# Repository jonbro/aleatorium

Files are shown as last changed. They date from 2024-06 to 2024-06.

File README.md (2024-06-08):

# Aleatorium

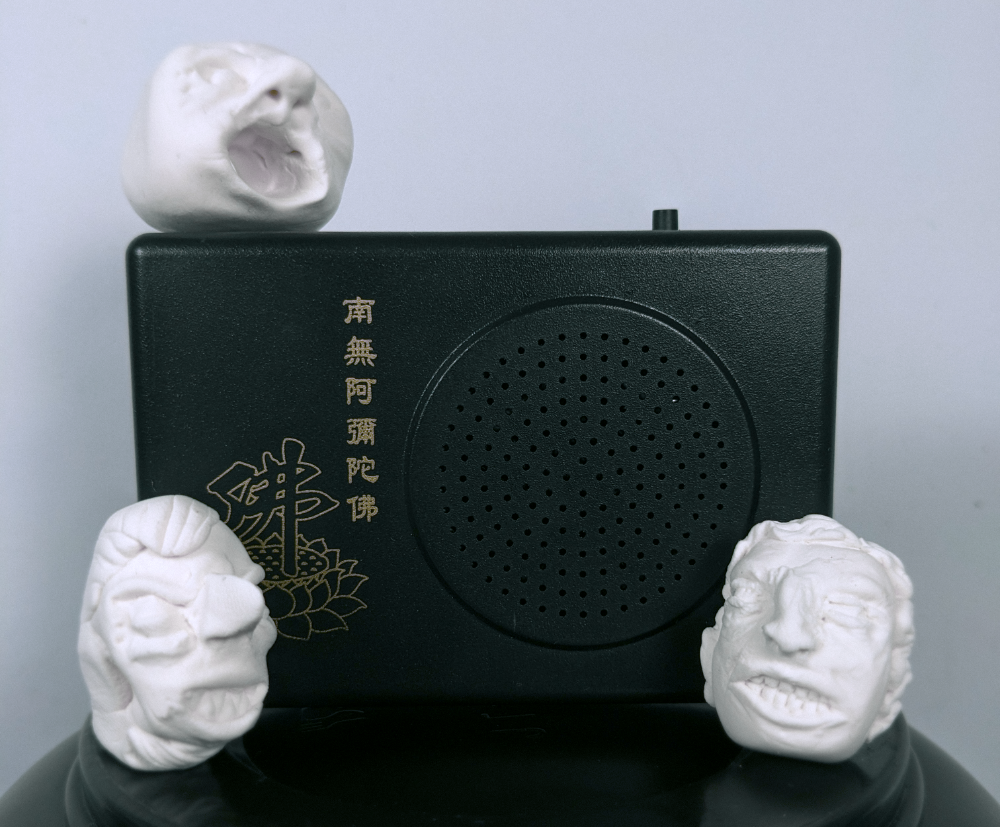
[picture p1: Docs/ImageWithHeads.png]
buddha box with heads


A lua scriptable buddha box board swap.

The hardware on this project is forked from [Eric Brombaugh's RP2040 boardswap for buddha boxes](https://github.com/emeb/RP2040_Projects/tree/main/buddhabox). I'm so glad he opensourced this, a programmable buddha machine is something that I've long wanted.

The firmware contains an lua scriptable 8 channel synthesizer and sequencer. The synth has the following features:
- oscilators from MI braids  
- 1 assignable lfo + 2 semi assignable Envs per voice
- lowpass filter per voice
- reverb & delay send per voice

The sequencer is a callback that is run at 96ppq. All further sequencing must be done by you.

You write new songs for aleatorium by connecting to it with usb, and loading lua scripts onto it with the [web based code editor](https://github.com/jonbro/aleatorium-editor).

## Scripting API

The scripting interface is quite simple, but there are some example files, [jam1](Firmware/jam1.lua) and [jam2](Firmware/jam2.lua). The [globals.lua file](Firmware/globals.lua) contains parameter constants for altering the synth voices.

```
-- setParam(voiceNumber, targetParameter, value)
-- voiceNumber: 0-7, the voice you want to set
-- targetParameter: use the params table from globals.lua
-- value: 0-255. Some parameters take a value from globals here, see below
setParam(0, param.timbre, 80)

-- playNote(voiceNumber, midiNoteValue)
-- voiceNumber: 0-7, the voice you want to set
-- midiNoteValue: 60 is middle c
playNote(0, 60)

-- tempoSync
-- called 96 times per quarternote. Currently there is no way to set the bpm other than recompling the firmware.

function tempoSync()

end

-- Special param targets:

-- shape - pick the voice shape, these are a subset of the oscilators from MI Braids
setParam(0, param.shape, shape.morph)

-- Env target - env1Target always goes to volume and the assigned target, env2Target only goes to the assigned target
setParam(0, param.env1Target, envTarget.cutoff)

-- LFO target - can be sent into params including env parameters
setParam(0, param.lfo1Target, lfoTarget.env12Attack)

```

## Editor notes

[A live version of the editor is available here](https://jonbro.github.io/aleatorium-editor/). Requires a non-firefox browser, due to using webserial. Make sure you connect to the device before you start trying to use it.

Use `ctrl+p` to send the current script to device and execute. You can run the following commands in the console:

```

-- save
-- provide a filename without quotes to save the file. This will add it to the set of songs that is looped through when pressing the button.
-- scripts are limited to a maximum of 16k
-- folders are not currently supported
save mysong.lua

-- load
-- provide a filename without quotes to load the file. This will replace the contents of the editor with the script.
-- folders are not currently supported. You cannot load the globals file.
load mysong.lua

-- del / rm
-- provide a filename without quotes to delete the file. This will remove it from the filesystem, and it will no longer be part of the songs on device
rm mysong.lua
```

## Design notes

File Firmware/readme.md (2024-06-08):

# A HEAP OF RANDOM NOTES FOR NOW. DEAL WITH IT :sunglasses:

`openocd -f interface/picoprobe.cfg -f target/rp2040.cfg -s tcl`
`cmake -G"NMake Makefiles" ..`
run vscode in developer / admistrator mode for access to nmake (developer command prompt for vs 2019)
check to make sure the "kit" is selected (`GCC for arm-none-eabi 10.2.1`)

see this as an option for installing the toolchain
https://github.com/ndabas/pico-setup-windows

*Resource Generation*
`>C:\Python27\python.exe resources_compiler.py resources/resources.py`

*NanoPB generation* 
`python nanopb\generator\nanopb_generator.py VoiceData.proto`
note the forward slashes, it does some kind of replacement on the path to convert to a module name

rates 2x 3/2x 1x 3/4x (triplets) 1/2x 1/4x 1/8x

we want to count up to 0xffffff 8 times per second? at 120bpm

sixteents per second, thirty seconds per second

bpm to bps = 
120 * (1 / 60) * (1/4)

bps to 32nds p sec

bps * 1/8

beats per sample

44100 * 32nds p sec

    "1:1", 1
    
    "1:2", 2
    "2:2", 3 (2*1)
    
    "1:3", 4
    "2:3", 5 
    "1:3", 6 (3*2)

    "1:4", 7
    "2:4", 8
    "3:4", 9
    "4:4", 10 (5*2)
  e

2,756.25
q8          q4
(44100<<8)/(60<<4) = q4

60*32 = 1920

local valTable = {}

for i=2,8 do
  for j=1,i do
   table.insert(valTable, j)
   table.insert(valTable, i)
  end
end

print("const uint8_t ConditionalEvery[".. #valTable .. "] = {\n" .. table.concat(valTable, ", ") .. "};")

        // simplify, lets load from a known good source
        uint32_t filesize = ((uint32_t*)AudioSampleSecondbloop)[0]&0xffffff;
        int16_t* wave = ((int16_t*)AudioSampleSecondbloop)+2;
        if(filesize == 0 || sampleSegment == SMP_COMPLETE)
        {
            memset(buffer, 0, SAMPLES_PER_BUFFER*2);
            return;
        }
        if(sampleOffset > filesize)
            sampleSegment = SMP_COMPLETE;
        if(sampleSegment == SMP_COMPLETE)
            return;
        for(int i=0;i<SAMPLES_PER_BUFFER;i++)
        {
            if(sampleOffset > filesize - 1)
            {
                sampleSegment = SMP_COMPLETE;
            }
            // int16_t wave;
            // ffs_seek(GetFilesystem(), file, sampleOffset*2);
            // ffs_read(GetFilesystem(), file, wave, 2);

            phase_ += phase_increment;
            sampleOffset+=(phase_>>25);
            phase_-=(phase_&(0xfe<<24));

            buffer[i] = wave[sampleOffset];
            
        }
        return;

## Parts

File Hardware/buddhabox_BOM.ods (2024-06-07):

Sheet: buddhabox
Source: | /home/ericb/Engineering/KBADC/kicad/buddhabox/buddhabox.kicad_sch
Date: | Tue 18 Jul 2023 10:48:48 AM MST
Tool: | Eeschema 6.0.11-3.fc36
Generator: | /usr/share/kicad/plugins/bom_csv_grouped_by_value.py
Component Count: | 50
Individual Components:
Item | Qty | Reference(s) | Value | Footprint | Datasheet
 |  | C1 | 10uf | Capacitor_SMD:C_0805_2012Metric | ~
 |  | C3 | 27pf | Capacitor_SMD:C_0402_1005Metric | ~
 |  | C4 | 27pf | Capacitor_SMD:C_0402_1005Metric | ~
 |  | C5 | 22uf | Capacitor_SMD:C_1210_3225Metric | ~
 |  | C6 | 0.1uf | Capacitor_SMD:C_0402_1005Metric | ~
 |  | C8 | 0.1uf | Capacitor_SMD:C_0402_1005Metric | ~
 |  | C9 | 0.1uf | Capacitor_SMD:C_0402_1005Metric | ~
 |  | C10 | 0.1uf | Capacitor_SMD:C_0402_1005Metric | ~
 |  | C11 | 0.1uf | Capacitor_SMD:C_0402_1005Metric | ~
 |  | C12 | 0.1uf | Capacitor_SMD:C_0402_1005Metric | ~
 |  | C13 | 0.1uf | Capacitor_SMD:C_0402_1005Metric | ~
 |  | C15 | 0.1uf | Capacitor_SMD:C_0402_1005Metric | ~
 |  | C16 | 10uf | Capacitor_SMD:C_0805_2012Metric | ~
 |  | C17 | 10uf | Capacitor_SMD:C_0805_2012Metric | ~
 |  | C18 | 0.1uf | Capacitor_SMD:C_0402_1005Metric | ~
 |  | C19 | 0.1uf | Capacitor_SMD:C_0402_1005Metric | ~
 |  | C20 | 10uf | Capacitor_SMD:C_0805_2012Metric | ~
 |  | C21 | 0.1uf | Capacitor_SMD:C_0402_1005Metric | ~
 |  | C22 | 1uf | Capacitor_SMD:C_0402_1005Metric | ~
 |  | C23 | 1uf | Capacitor_SMD:C_0402_1005Metric | ~
 |  | C24 | 220pf | Capacitor_SMD:C_0402_1005Metric | ~
 |  | C25 | 0.1uf | Capacitor_SMD:C_0402_1005Metric | ~
 |  | C26 | 220pf | Capacitor_SMD:C_0402_1005Metric | ~
 |  | D1 | BAT54C | Package_TO_SOT_SMD:SOT-23 | http://www.diodes.com/_files/datasheets/ds11005.pdf
 |  | D3 | LED Green | LED_SMD:LED_0603_1608Metric | ~
 |  | FB1 | 1k | Inductor_SMD:L_0402_1005Metric | ~
 |  | FB2 | 1k | Inductor_SMD:L_0402_1005Metric | ~
 |  | FB3 | 1k | Inductor_SMD:L_0402_1005Metric | ~
 |  | J1 | Serial | Connector_PinHeader_2.54mm:PinHeader_1x02_P2.54mm_Vertical | ~
 |  | J2 | SWD | Connector_PinHeader_2.54mm:PinHeader_1x05_P2.54mm_Vertical | ~
 |  | J3 | USB_B_Micro | Connector_USB:USB_Micro-B_Amphenol_10103594-0001LF_Horizontal | ~
 |  | J4 | Speaker | Connector_PinHeader_2.54mm:PinHeader_1x02_P2.54mm_Vertical | ~
 |  | J5 | Battery | Connector_PinHeader_2.54mm:PinHeader_1x02_P2.54mm_Vertical | ~
 |  | L1 | 3.3uH | Inductor_SMD:L_Taiyo-Yuden_MD-2020 | MDMK2020T3R3MM
 |  | R2 | 1k | Resistor_SMD:R_0402_1005Metric | ~
 |  | R6 | 1k | Resistor_SMD:R_0402_1005Metric | ~
 |  | R9 | 10k | Resistor_SMD:R_0402_1005Metric | ~
 |  | R10 | 1k | Resistor_SMD:R_0402_1005Metric | ~
 |  | R11 | 100 | Resistor_SMD:R_0402_1005Metric | ~
 |  | R13 | 27.5 | Resistor_SMD:R_0402_1005Metric | ~
 |  | R14 | 27.5 | Resistor_SMD:R_0402_1005Metric | ~
 |  | RV1 | RV12 | emeb_library:RV12 | ~
 |  | SW1 | SW_Push | Button_Switch_SMD:SW_Push_1P1T_NO_CK_KMR2 | ~
 |  | SW3 | SW_Push | Button_Switch_SMD:SW_Push_1P1T_NO_CK_KMR2 | ~
 |  | SW4 | SW_Push | Button_Switch_THT:SW_Tactile_SPST_Angled_PTS645Vx83-2LFS | ~
 |  | U1 | TPS61291DRVR | emeb_library:SON65P200X200X80-7N
 |  | U3 | RP2040 | emeb_library:RP2040
 |  | U4 | PAM8302AAD | Package_SO:TSSOP-8_3x3mm_P0.65mm | https://www.diodes.com/assets/Datasheets/PAM8302A.pdf
 |  | U5 | W25Q32JVZPIQ | Package_SON:WSON-8-1EP_6x5mm_P1.27mm_EP3.4x4.3mm | http://www.winbond.com/resource-files/w25q32jv%20revg%2003272018%20plus.pdf
 |  | Y1 | Crystal_4pin_SMD | Crystal:Crystal_SMD_3225-4Pin_3.2x2.5mm
Collated Components:
Item | Qty | Reference(s) | Value | Footprint | Datasheet
1 | 4 | C1, C16, C17, C20 | 10uf | Capacitor_SMD:C_0805_2012Metric | ~
2 | 2 | C3, C4 | 27pf | Capacitor_SMD:C_0402_1005Metric | ~
3 | 1 | C5 | 22uf | Capacitor_SMD:C_1210_3225Metric | ~
4 | 12 | C6, C8, C9, C10, C11, C12, C13, C15, C18, C19, C21, C25 | 0.1uf | Capacitor_SMD:C_0402_1005Metric | ~
5 | 2 | C22, C23 | 1uf | Capacitor_SMD:C_0402_1005Metric | ~
6 | 2 | C24, C26 | 220pf | Capacitor_SMD:C_0402_1005Metric | ~
7 | 1 | D1 | BAT54C | Package_TO_SOT_SMD:SOT-23 | http://www.diodes.com/_files/datasheets/ds11005.pdf
8 | 1 | D3 | LED Green | LED_SMD:LED_0603_1608Metric | ~
9 | 3 | FB1, FB2, FB3 | 1k | Inductor_SMD:L_0402_1005Metric | ~
10 | 1 | J1 | Serial | Connector_PinHeader_2.54mm:PinHeader_1x02_P2.54mm_Vertical | ~
11 | 1 | J2 | SWD | Connector_PinHeader_2.54mm:PinHeader_1x05_P2.54mm_Vertical | ~
12 | 1 | J3 | USB_B_Micro | Connector_USB:USB_Micro-B_Amphenol_10103594-0001LF_Horizontal | ~
13 | 1 | J4 | Speaker | Connector_PinHeader_2.54mm:PinHeader_1x02_P2.54mm_Vertical | ~
14 | 1 | J5 | Battery | Connector_PinHeader_2.54mm:PinHeader_1x02_P2.54mm_Vertical | ~
15 | 1 | L1 | 3.3uH | Inductor_SMD:L_Taiyo-Yuden_MD-2020 | MDMK2020T3R3MM
16 | 3 | R2, R6, R10 | 1k | Resistor_SMD:R_0402_1005Metric | ~
17 | 1 | R9 | 10k | Resistor_SMD:R_0402_1005Metric | ~
18 | 1 | R11 | 100 | Resistor_SMD:R_0402_1005Metric | ~
19 | 2 | R13, R14 | 27.5 | Resistor_SMD:R_0402_1005Metric | ~
20 | 1 | RV1 | RV12 | emeb_library:RV12 | ~
21 | 2 | SW1, SW3 | SW_Push | Button_Switch_SMD:SW_Push_1P1T_NO_CK_KMR2 | ~
22 | 1 | SW4 | SW_Push | Button_Switch_THT:SW_Tactile_SPST_Angled_PTS645Vx83-2LFS | ~
23 | 1 | U1 | TPS61291DRVR | emeb_library:SON65P200X200X80-7N
24 | 1 | U3 | RP2040 | emeb_library:RP2040
25 | 1 | U4 | PAM8302AAD | Package_SO:TSSOP-8_3x3mm_P0.65mm | https://www.diodes.com/assets/Datasheets/PAM8302A.pdf
26 | 1 | U5 | W25Q32JVZPIQ | Package_SON:WSON-8-1EP_6x5mm_P1.27mm_EP3.4x4.3mm | http://www.winbond.com/resource-files/w25q32jv%20revg%2003272018%20plus.pdf
27 | 1 | Y1 | Crystal_4pin_SMD | Crystal:Crystal_SMD_3225-4Pin_3.2x2.5mm

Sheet: Sheet2
Item | Qty | Reference(s) | Value | Footprint | Picked | placed
1 | 4 | C1, C16, C17, C20 | 10uf | Capacitor_SMD:C_0805_2012Metric | y | 4
2 | 2 | C3, C4 | 27pf | Capacitor_SMD:C_0402_1005Metric | y | 2
3 | 1 | C5 | 22uf | Capacitor_SMD:C_1210_3225Metric | y | 1
4 | 12 | C6, C8, C9, C10, C11, C12, C13, C15, C18, C19, C21, C25 | 0.1uf | Capacitor_SMD:C_0402_1005Metric | y | 12
5 | 2 | C22, C23 | 1uf | Capacitor_SMD:C_0402_1005Metric | y | 2
6 | 2 | C24, C26 | 220pf | Capacitor_SMD:C_0402_1005Metric | y | 2
7 | 1 | D1 | BAT54C | Package_TO_SOT_SMD:SOT-23 | y | 1 | Wrong pkg!
8 | 1 | D3 | LED Green | LED_SMD:LED_0603_1608Metric | y | 1
9 | 3 | FB1, FB2, FB3 | 1k | Inductor_SMD:L_0402_1005Metric | ehh | 3
10 | 1 | J1 | Serial | Connector_PinHeader_2.54mm:PinHeader_1x02_P2.54mm_Vertical | y
11 | 1 | J2 | SWD | Connector_PinHeader_2.54mm:PinHeader_1x05_P2.54mm_Vertical | y
12 | 1 | J3 | USB_B_Micro | Connector_USB:USB_Micro-B_Amphenol_10103594-0001LF_Horizontal | y | 1
13 | 1 | J4 | Speaker | Connector_PinHeader_2.54mm:PinHeader_1x02_P2.54mm_Vertical | y
14 | 1 | J5 | Battery | Connector_PinHeader_2.54mm:PinHeader_1x02_P2.54mm_Vertical | y
15 | 1 | L1 | 3.3uH | Inductor_SMD:L_Taiyo-Yuden_MD-2020 | y | 1
16 | 3 | R2, R6, R10 | 1k | Resistor_SMD:R_0402_1005Metric | y | 3
17 | 1 | R9 | 10k | Resistor_SMD:R_0402_1005Metric | y | 1
18 | 1 | R11 | 100 | Resistor_SMD:R_0402_1005Metric | y | 1
19 | 2 | R13, R14 | 27.5 | Resistor_SMD:R_0402_1005Metric | 22 | 2
20 | 1 | RV1 | RV12 | emeb_library:RV12 | y
21 | 2 | SW1, SW3 | SW_Push | Button_Switch_SMD:SW_Push_1P1T_NO_CK_KMR2 | y | 2
22 | 1 | SW4 | SW_Push | Button_Switch_THT:SW_Tactile_SPST_Angled_PTS645Vx83-2LFS | y
23 | 1 | U1 | TPS61291DRVR | emeb_library:SON65P200X200X80-7N | y | 1
24 | 1 | U3 | RP2040 | emeb_library:RP2040 | y
25 | 1 | U4 | PAM8302AAD | Package_SO:TSSOP-8_3x3mm_P0.65mm | y | 1
26 | 1 | U5 | W25Q32JVZPIQ | Package_SON:WSON-8-1EP_6x5mm_P1.27mm_EP3.4x4.3mm | y
27 | 1 | Y1 | Crystal_4pin_SMD | Crystal:Crystal_SMD_3225-4Pin_3.2x2.5mm | y | 1

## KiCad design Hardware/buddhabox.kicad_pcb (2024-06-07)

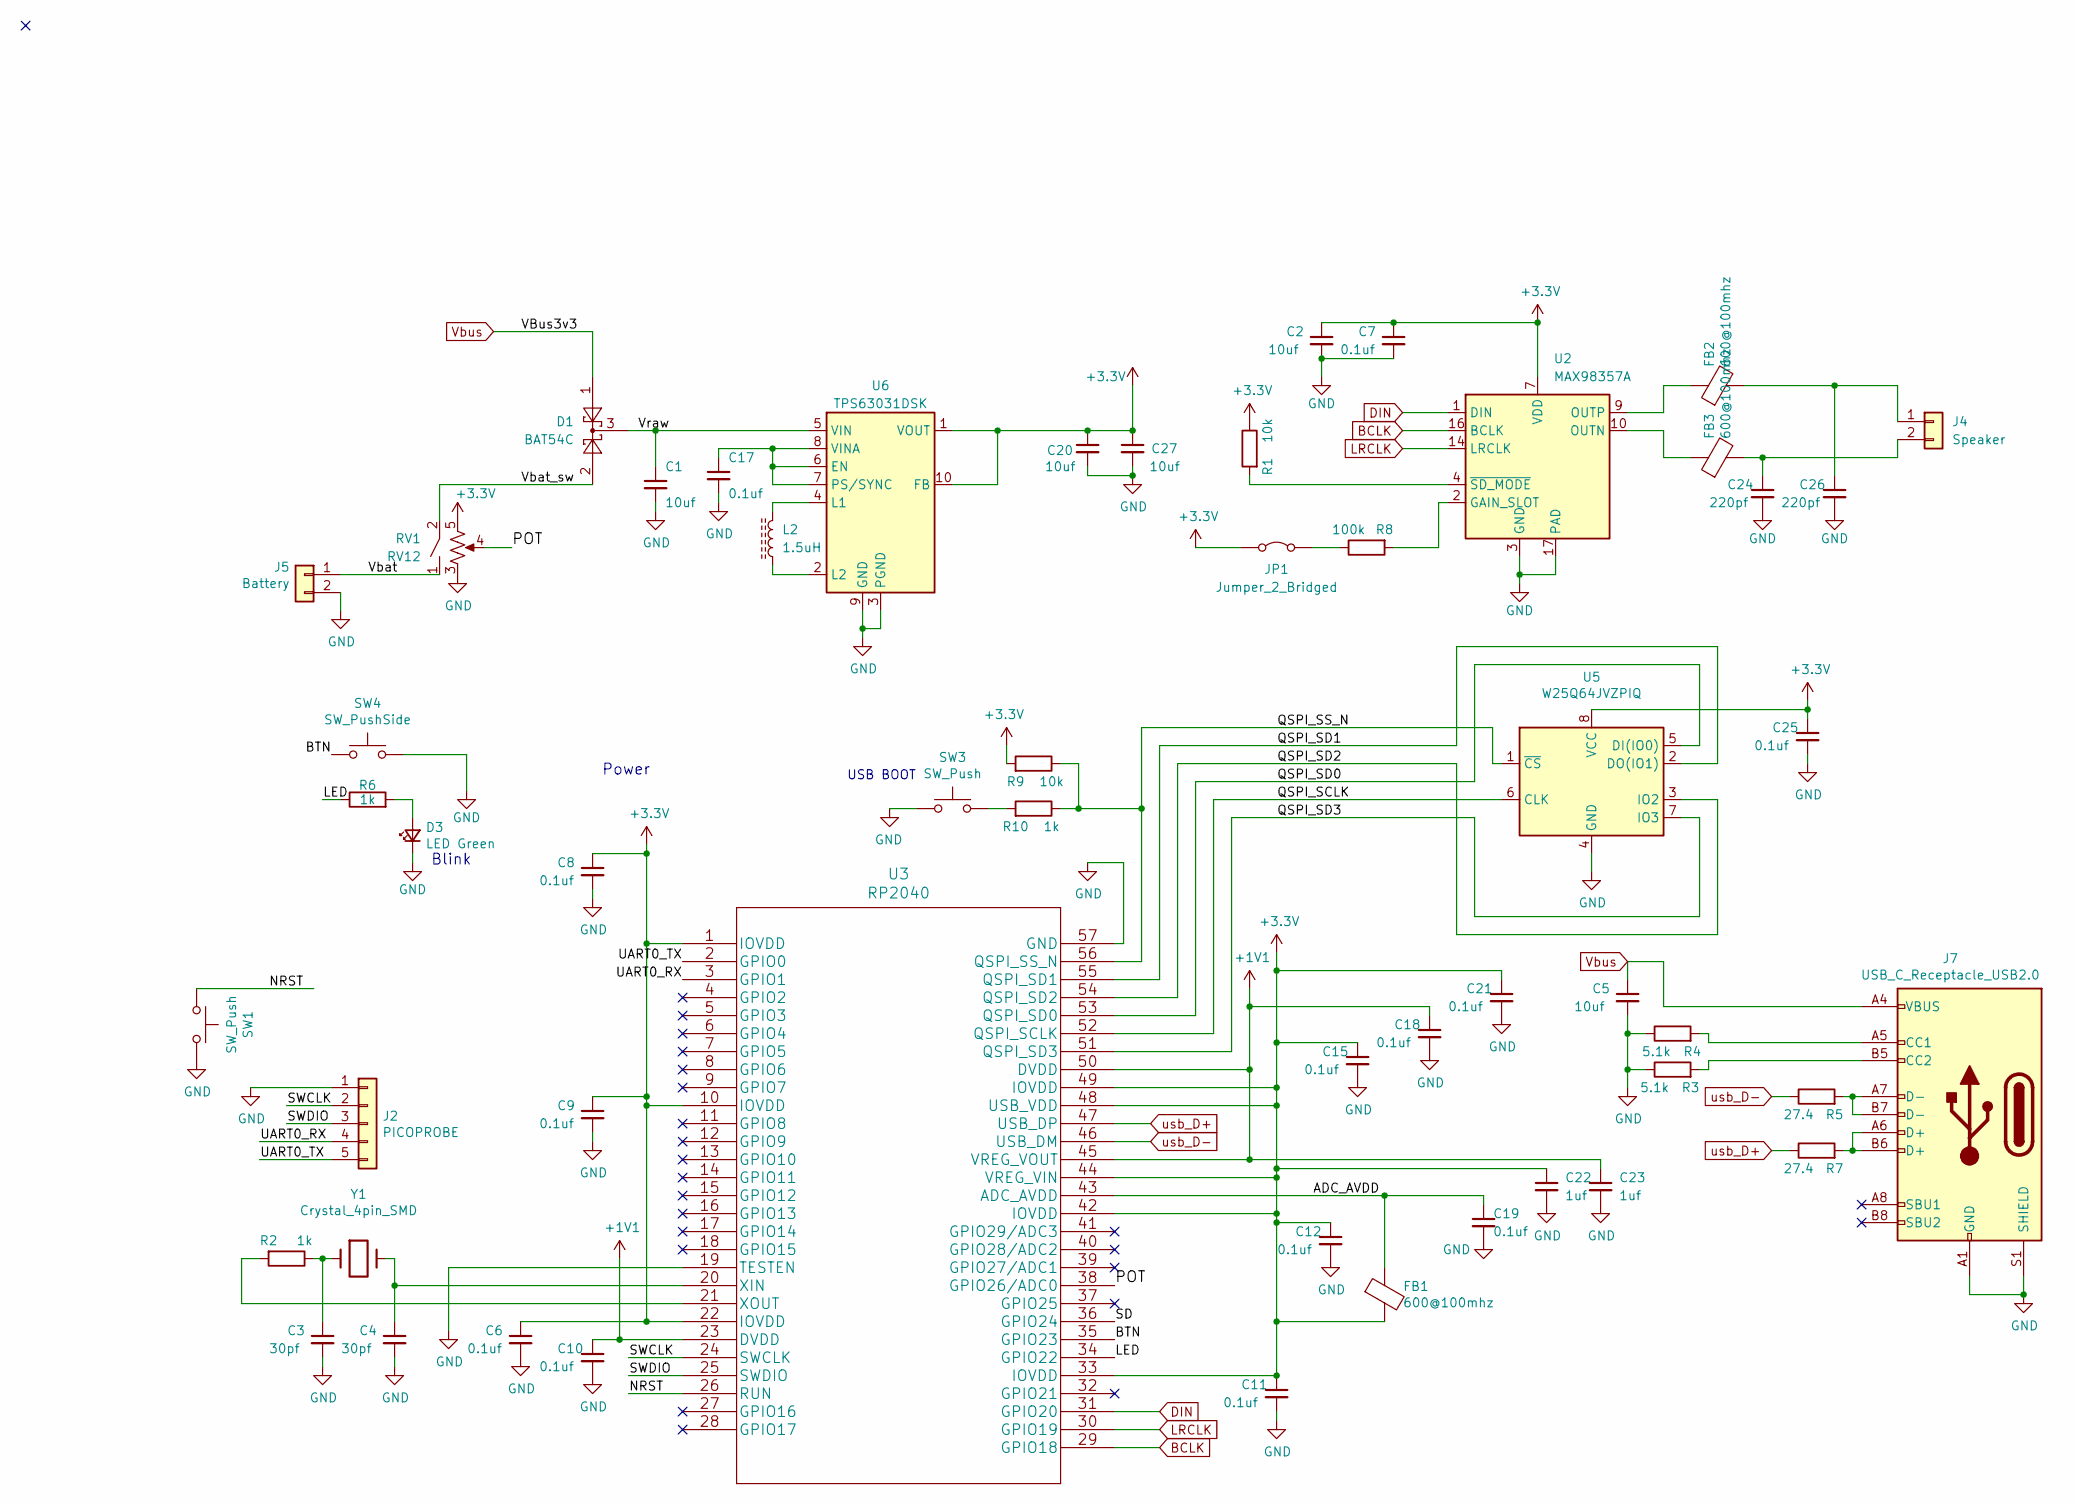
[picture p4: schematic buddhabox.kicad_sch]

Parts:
C1, C2, C5, C20, C27: 10uf; C_0402_1005Metric; LCSC C15525
C3, C4: 30pf; C_0603_1608Metric; LCSC C1658
C6, C7, C8, C9, C10, C11, C12, C15, C17, C18, C19, C21, C25: 0.1uf; C_0402_1005Metric; LCSC C1525
C22, C23: 1uf; C_0402_1005Metric; LCSC C52923
C24, C26: 220pf; C_0402_1005Metric; LCSC C1530
D1: BAT54C; SOT-23; LCSC C556168
D3: LED Green; LED_0603_1608Metric; LCSC C2286
FB1, FB2, FB3: 600@100mhz; L_0603_1608Metric; LCSC C1002
J2: PICOPROBE; PinHeader_1x05_P2.54mm_Vertical
J4: Speaker; PinHeader_1x02_P2.54mm_Vertical
J5: Battery; PinHeader_1x02_P2.54mm_Vertical
J7: USB_C_Receptacle_USB2.0; USB-C_SMD-TYPE-C-31-M-12; LCSC C165948
JP1: Jumper_2_Bridged; SolderJumper-2_P1.3mm_Bridged_Pad1.0x1.5mm
L2: 1.5uH; L_Coilcraft_LPS3010; LCSC C17382749
R1, R9: 10k; R_0402_1005Metric; LCSC C25744
R2, R6, R10: 1k; R_0402_1005Metric; LCSC C11702
R3, R4: 5.1k; R_0402_1005Metric; LCSC C25905
R5, R7: 27.4; R_0402_1005Metric; LCSC C31439
R8: 100k; R_0805_2012Metric; LCSC C149504
RV1: RV12
SW1, SW3: SW_Push; SW_Push_1P1T_NO_CK_KMR2; LCSC C221675
SW4: SW_PushSide; SW_Tactile_SPST_Angled_PTS645Vx83-2LFS; LCSC DNP
U2: MAX98357A; TQFN-16-1EP_3x3mm_P0.5mm_EP1.23x1.23mm; LCSC C910544
U3: RP2040; LCSC C2040
U5: W25Q64JVZPIQ; WSON-8-1EP_6x5mm_P1.27mm_EP3.4x4.3mm; LCSC C2940197
U6: TPS63031DSK; WSON-10-1EP_2.5x2.5mm_P0.5mm_EP1.2x2mm; LCSC C15516
Y1: Crystal_4pin_SMD; Crystal_SMD_3225-4Pin_3.2x2.5mm; LCSC C9002

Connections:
+1V1: C10.1, C18.1, C23.1, U3.23 (DVDD), U3.45 (VREG_VOUT), U3.50 (DVDD)
+3.3V: C2.1, C6.1, C7.1, C8.1, C9.1, C11.1, C12.1, C15.1, C20.1, C21.1, C22.1, C25.1, C27.1, FB1.2, JP1.1 (A), R1.1, R9.2, RV1.5, U2.7 (VDD), U2.8 (VDD), U3.1 (IOVDD), U3.10 (IOVDD), U3.22 (IOVDD), U3.33 (IOVDD), U3.42 (IOVDD), U3.44 (VREG_VIN), U3.48 (USB_VDD), U3.49 (IOVDD), U5.8 (VCC), U6.1 (VOUT), U6.10 (FB)
/ADC_AVDD: C19.1, FB1.1, U3.43 (ADC_AVDD)
/BTN: SW4.2, U3.35 (GPIO23)
/LED: R6.1, U3.34 (GPIO22)
/NRST: SW1.1, U3.26 (RUN)
/POT: RV1.4, U3.38 (GPIO26/ADC0)
/QSPI_SCLK: U3.52 (QSPI_SCLK), U5.6 (CLK)
/QSPI_SD0: U3.53 (QSPI_SD0), U5.5 (DI(IO0))
/QSPI_SD1: U3.55 (QSPI_SD1), U5.2 (DO(IO1))
/QSPI_SD2: U3.54 (QSPI_SD2), U5.3 (IO2)
/QSPI_SD3: U3.51 (QSPI_SD3), U5.7 (IO3)
/QSPI_SS_N: R9.1, R10.1, U3.56 (QSPI_SS_N), U5.1 (~CS)
/SD: U3.36 (GPIO24)
/SWCLK: J2.2, U3.24 (SWCLK)
/SWDIO: J2.3, U3.25 (SWDIO)
/UART0_RX: J2.4, U3.3 (GPIO1)
/UART0_TX: J2.5, U3.2 (GPIO0)
/Vbat: J5.1, RV1.1
/Vbat_sw: D1.2, RV1.2
/Vraw: C1.1, D1.3, U6.5 (VIN)
BCLK: U2.16 (BCLK), U3.29 (GPIO18)
DIN: U2.1 (DIN), U3.31 (GPIO20)
GND: C1.2, C2.2, C3.2, C4.2, C5.2, C6.2, C7.2, C8.2, C9.2, C10.2, C11.2, C12.2, C15.2, C17.2, C18.2, C19.2, C20.2, C21.2, C22.2, C23.2, C24.2, C25.2, C26.2, C27.2, D3.1 (K), J2.1, J5.2, J7.A1 (GND), J7.A12 (GND), J7.B1 (GND), J7.B12 (GND), J7.S1 (SHIELD), R3.1, R4.1, RV1.3, SW1.2, SW3.2, SW4.1, U2.3 (GND), U2.11 (GND), U2.15 (GND), U2.17 (PAD), U3.19 (TESTEN), U3.57 (GND), U5.4 (GND), U6.3 (PGND), U6.9 (GND), U6.11 (PGND)
LRCLK: U2.14 (LRCLK), U3.30 (GPIO19)
unnamed: C3.1, R2.1, Y1.1
unnamed: D3.2 (A), R6.2
unnamed: C26.1, FB2.2, J4.1
unnamed: C24.1, FB3.2, J4.2
unnamed: J7.A5 (CC1), R4.2
unnamed: J7.B5 (CC2), R3.2
unnamed: J7.A6 (D+), J7.B6 (D+), R7.2
unnamed: J7.A7 (D-), J7.B7 (D-), R5.2
unnamed: JP1.2 (B), R8.1
unnamed: R10.2, SW3.1
unnamed: R8.2, U2.2 (GAIN_SLOT)
unnamed: FB3.1, U2.10 (OUTN)
unnamed: FB2.1, U2.9 (OUTP)
unnamed: R1.2, U2.4 (~SD_MODE)
unnamed: C4.1, U3.20 (XIN), Y1.3
unnamed: R2.2, U3.21 (XOUT)
unnamed: C17.1, U6.6 (EN), U6.7 (PS/SYNC), U6.8 (VINA)
unnamed: L2.2, U6.4 (L1)
unnamed: L2.1, U6.2 (L2)
Vbus: C5.1, D1.1, J7.A4 (VBUS), J7.A9 (VBUS), J7.B4 (VBUS), J7.B9 (VBUS)
usb_D+: R7.1, U3.47 (USB_DP)
usb_D-: R5.1, U3.46 (USB_DM)

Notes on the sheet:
USB BOOT
Blink
Power

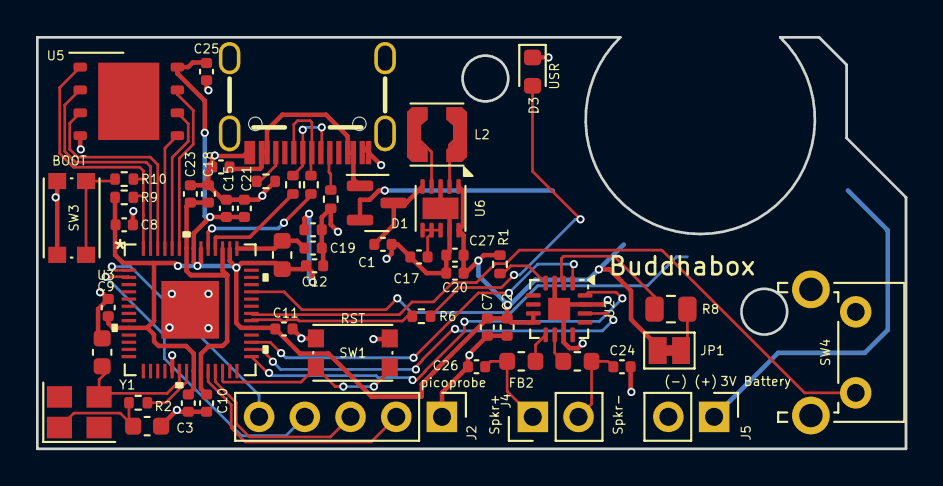
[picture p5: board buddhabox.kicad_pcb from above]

Board: 2 copper layers, 48.3 x 22.9 mm, 54 parts (1 on the bottom side), 46 nets.

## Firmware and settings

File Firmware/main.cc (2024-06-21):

#include <stdio.h>
#include "pico/stdlib.h"
#include "pico/sleep.h"
#include "hardware/i2c.h"
#include "hardware/dma.h"
#include "hardware/irq.h"
#include "hardware/pio.h"
#include "hardware/adc.h"
#include "hardware/flash.h"
#include "pico/multicore.h"
#include "pico/util/queue.h"
#include "hardware/structs/scb.h"
#include "hardware/rosc.h"

#include <math.h>

#include "hardware/clocks.h"
#include "hardware/structs/clocks.h"
#include "input_output_copy_i2s.pio.h"
#include "ws2812.pio.h"

extern "C" {
#include "ssd1306.h"
}
#include "m6x118pt7b.h"

#include "GrooveBox.h"
#include "audio/macro_oscillator.h"

#include "ws2812.h"
#include "hardware.h"
#include <pb_encode.h>
#include <pb_decode.h>
#include "USBSerialDevice.h"
#include "multicore_support.h"
#include "GlobalDefines.h"
#include "bsp/board.h"
#include "lua.hpp"
#include "filesystem.h"
#include "printwrapper.h"
#include "globals.lua.h"

using namespace braids;


#define USING_DEMO_BOARD 0

void on_usb_microphone_tx_ready();

static float clip(float value)
{
    value = value < -1.0f ? -1.0f : value;
    value = value > +1.0f ? +1.0f : value;
    return value;
}

int dma_chan_input;
int dma_chan_output;
uint sm;

bool audioInReady = false;
bool audioOutReady = false;
uint32_t capture_buf[SAMPLES_PER_BLOCK*BLOCKS_PER_SEND*2];
uint32_t output_buf[SAMPLES_PER_BLOCK*BLOCKS_PER_SEND*2];

int outBufOffset = 0;
int inBufOffset = 0;
int audioGenOffset = 0;
GrooveBox gbox;
USBSerialDevice usbSerialDevice;
auto_init_mutex(audioProcessMutex);

int triCount = 0;
int note = 60;


/*
* double buffered audio - if the signal that the next frame of audio hasn't completed sending,
*/ 

void __not_in_flash_func(dma_input_handler)() {
    if (dma_hw->ints0 & (1u<<dma_chan_input)) {
        dma_hw->ints0 = (1u << dma_chan_input);
        dma_channel_set_write_addr(dma_chan_input, capture_buf+(inBufOffset)*SAMPLES_PER_SEND, true);
        uint32_t x;
        if(mutex_try_enter(&audioProcessMutex, &x))
        {
            inBufOffset = (inBufOffset+1)%2;
            audioInReady = true;
            mutex_exit(&audioProcessMutex);
        }
    }
}

void __not_in_flash_func(dma_output_handler)() {
    if (dma_hw->ints0 & (1u<<dma_chan_output)) {
        dma_hw->ints0 = 1u << dma_chan_output;
        dma_channel_set_read_addr(dma_chan_output, output_buf+(outBufOffset)*SAMPLES_PER_SEND, true);
        uint32_t x;
        if(mutex_try_enter(&audioProcessMutex, &x))
        {
            outBufOffset = (outBufOffset+1)%2;
            audioOutReady = true;
            mutex_exit(&audioProcessMutex);
        }
    }
}

int flashReadPos = 0;

static inline void put_pixel(uint32_t pixel_grb) {
    pio_sm_put_blocking(pio0, 0, pixel_grb << 8u);
}

bool needsScreenupdate;
bool repeating_timer_callback(struct repeating_timer *t) {
    needsScreenupdate = true;
    return true;
}

bool usb_timer_callback(struct repeating_timer *t) {
    //usbaudio_update();
    return true;
}

bool screen_flip_ready = false;
int drawY = 0;
void __not_in_flash_func(draw_screen)()
{
    // this needs to be called here, because the multicore launch relies on
    // the fifo being functional
    sleep_ms(20);
    multicore_lockout_victim_init();
    while(true)
    {
        queue_entry_t entry;
        if(queue_try_remove(&signal_queue, &entry))
        {
            if(entry.renderInstrument >= 0)
            {
                gbox.instruments[entry.renderInstrument].Render(entry.sync_buffer, entry.workBuffer, 64);
                queue_entry_complete_t result;
                result.screenFlipComplete = false;
                result.renderInstrumentComplete = true;
                queue_add_blocking(&renderCompleteQueue, &result);
            }
        }
    }
}


void configure_audio_driver()
{
    /**/
    PIO pio = pio1;
    uint offset = pio_add_program(pio, &input_output_copy_i2s_program);
    printf("loaded program at offset: %i\n", offset);
    sm = pio_claim_unused_sm(pio, true);
    printf("claimed sm: %i\n", sm); //I2S_DATA_PIN
    int sample_freq = 32000;
    printf("setting pio freq %d\n", (int) sample_freq);
    uint32_t system_clock_frequency = clock_get_hz(clk_sys);
    assert(system_clock_frequency < 0x40000000);

    uint32_t divider = system_clock_frequency*2 / sample_freq; // avoid arithmetic overflow
    // uint32_t divider = system_clock_frequency/(sample_freq*3*32);
    printf("System clock at %u, I2S clock divider 0x%x/256\n", (uint) system_clock_frequency, (uint)divider);
    assert(divider < 0x1000000);
    input_output_copy_i2s_program_init(pio, sm, offset, I2S_DATA_PIN, I2S_DATA_PIN+1, I2S_BCLK_PIN);
    pio_sm_set_enabled(pio, sm, true);
    pio_sm_set_clkdiv_int_frac(pio, sm, divider >> 8u, divider & 0xffu);

    // just use a dma to pull the data out. Whee!
    dma_chan_input = dma_claim_unused_channel(true);
    dma_channel_config c = dma_channel_get_default_config(dma_chan_input);
    channel_config_set_read_increment(&c,false);
    // increment on write
    channel_config_set_write_increment(&c,true);
    channel_config_set_dreq(&c,pio_get_dreq(pio,sm,false));
    channel_config_set_transfer_data_size(&c, DMA_SIZE_32);

    dma_channel_configure(
        dma_chan_input,
        &c,
        capture_buf, // Destination pointer
        &pio->rxf[sm], // Source pointer
        SAMPLES_PER_SEND, // Number of transfers
        true// Start immediately
    );
    // Tell the DMA to raise IRQ line 0 when the channel finishes a block
    dma_channel_set_irq0_enabled(dma_chan_input, true);

    // Configure the processor to run dma_handler() when DMA IRQ 0 is asserted
    irq_add_shared_handler(DMA_IRQ_0, dma_input_handler, PICO_SHARED_IRQ_HANDLER_DEFAULT_ORDER_PRIORITY-1);
    irq_set_enabled(DMA_IRQ_0, true);
    // need another dma channel for output
    dma_chan_output = dma_claim_unused_channel(true);
    dma_channel_config cc = dma_channel_get_default_config(dma_chan_output);
    // increment on read, but not on write
    channel_config_set_read_increment(&cc,true);
    channel_config_set_write_increment(&cc,false);
    channel_config_set_dreq(&cc,pio_get_dreq(pio,sm,true));
    channel_config_set_transfer_data_size(&cc, DMA_SIZE_32);
    dma_channel_configure(
        dma_chan_output,
        &cc,
        &pio->txf[sm], // Destination pointer
        output_buf, // Source pointer
        SAMPLES_PER_SEND, // Number of transfers
        true// Start immediately
    );
    dma_channel_set_irq0_enabled(dma_chan_output, true);
    // Configure the processor to run dma_handler() when DMA IRQ 0 is asserted
    irq_add_shared_handler(DMA_IRQ_0, dma_output_handler, PICO_SHARED_IRQ_HANDLER_DEFAULT_ORDER_PRIORITY-2);
    irq_set_enabled(DMA_IRQ_0, true);
}

uint8_t adc1_prev;
uint8_t adc2_prev;

#define LINE_IN_DETECT 24
#define HEADPHONE_DETECT 16

// Variable that holds the current position in the sequence.
uint32_t note_pos = 0;

// Store example melody as an array of note values
uint8_t note_sequence[] =
{
  74,78,81,86,90,93,98,102,57,61,66,69,73,78,81,85,88,92,97,100,97,92,88,85,81,78,
  74,69,66,62,57,62,66,69,74,78,81,86,90,93,97,102,97,93,90,85,81,78,73,68,64,61,
  56,61,64,68,74,78,81,86,90,93,98,102
};


uint32_t color[25];
const uint8_t gamma8[] = {
    0,  0,  0,  0,  0,  0,  0,  0,  0,  0,  0,  0,  0,  0,  0,  0,
    0,  0,  0,  0,  0,  0,  0,  0,  0,  0,  0,  0,  1,  1,  1,  1,
    1,  1,  1,  1,  1,  1,  1,  1,  1,  2,  2,  2,  2,  2,  2,  2,
    2,  3,  3,  3,  3,  3,  3,  3,  4,  4,  4,  4,  4,  5,  5,  5,
    5,  6,  6,  6,  6,  7,  7,  7,  7,  8,  8,  8,  9,  9,  9, 10,
    10, 10, 11, 11, 11, 12, 12, 13, 13, 13, 14, 14, 15, 15, 16, 16,
    17, 17, 18, 18, 19, 19, 20, 20, 21, 21, 22, 22, 23, 24, 24, 25,
    25, 26, 27, 27, 28, 29, 29, 30, 31, 32, 32, 33, 34, 35, 35, 36,
    37, 38, 39, 39, 40, 41, 42, 43, 44, 45, 46, 47, 48, 49, 50, 50,
    51, 52, 54, 55, 56, 57, 58, 59, 60, 61, 62, 63, 64, 66, 67, 68,
    69, 70, 72, 73, 74, 75, 77, 78, 79, 81, 82, 83, 85, 86, 87, 89,
    90, 92, 93, 95, 96, 98, 99,101,102,104,105,107,109,110,112,114,
    115,117,119,120,122,124,126,127,129,131,133,135,137,138,140,142,
    144,146,148,150,152,154,156,158,160,162,164,167,169,171,173,175,
    177,180,182,184,186,189,191,193,196,198,200,203,205,208,210,213,
    215,218,220,223,225,228,231,233,236,239,241,244,247,249,252,255 };

static inline uint32_t gammarbg_u32(uint8_t r, uint8_t g, uint8_t b)
{
    return urgb_u32(gamma8[r], gamma8[g], gamma8[b]);
}

static int l_setLed(lua_State *L)
{
    int8_t index = luaL_checknumber(L, 1);
    index = index<0?0:index;
    index = index > 24?24:index;
    uint8_t r = luaL_checknumber(L, 2);
    uint8_t g = luaL_checknumber(L, 3);
    uint8_t b = luaL_checknumber(L, 4);
    color[index] = gammarbg_u32(r,g,b);
    return 0;
}
static int l_playNote(lua_State *L)
{
    int8_t voiceIndex = luaL_checknumber(L, 1);
    gbox.instruments[voiceIndex].NoteOn(0, luaL_checknumber(L, 2), 0, 0, false, gbox.patterns[voiceIndex]);
    return 0;
}
static int l_setParam(lua_State *L)
{
    int8_t index = luaL_checknumber(L, 1);
    uint8_t& current_a = gbox.patterns[index].GetParam(luaL_checknumber(L, 2), 0, 0);
    current_a = luaL_checknumber(L, 3);
    return 0;
}
static int l_getPot(lua_State *L)
{
    lua_pushnumber(L, gbox.globalVolume);
    return 1;
}
static int l_resetParams(lua_State *L)
{
    for(int i=0;i<8;i++)
    {
        gbox.patterns[i].InitDefaults();
    }
    return 0;
}

char incomingData[16384];
int charCount = 0;

static int SaveFile()
{
    lfs_file_t file;
    // extract the filename
    char *s = incomingData;
    int searchCount = charCount;
    while(searchCount--)
    {
        if( *s++ == '^' )
        {
            if( *s++ == '^' )
            {
                if(*s == 'S')
                {
                    s++;
                    break;
                }
            }
        }
    }
    char filename[64];
    char *fn = filename;
    // extract the filename
    // TODO: deal with buffer overflow
    while(searchCount--)
    {
        if(*s != '^')
        {
            *fn = *s;
            s++; fn++;
        }
        else
        {
            s++;
            break;
        }
    }
    *fn = 0;
    lfs_file_open(GetFilesystem(), &file, filename, LFS_O_RDWR | LFS_O_CREAT);
    // reset back to zero in case we've been appending to the end
    lfs_file_truncate(GetFilesystem(), &file, 0);
    lfs_file_rewind(GetFilesystem(), &file);
    lfs_file_write(GetFilesystem(), &file, s, searchCount);
    lfs_file_close(GetFilesystem(), &file);
    lfs_file_open(GetFilesystem(), &file, filename, LFS_O_RDONLY);
    lfs_soff_t size = lfs_file_size(GetFilesystem(), &file);
    lfs_file_close(GetFilesystem(), &file);
    printf("wrote file: %s - %i bytes\n", filename, size);
    return 0;
}

static int LoadFile()
{
    lfs_file_t file;
    // extract the filename
    char *s = incomingData;
    int searchCount = charCount;
    while(searchCount--)
    {
        if( *s++ == '^' )
        {
            if( *s++ == '^' )
            {
                if(*s == 'L')
                {
                    s++;
                    break;
                }
            }
        }
    }
    char filename[64];
    char *fn = filename;
    // extract the filename
    // TODO: deal with buffer overflow
    while(searchCount--)
    {
        if(*s != 0x03)
        {
            *fn = *s;
            s++; fn++;
        }
        else
        {
            break;
        }
    }
    *fn = 0;
    printf("attempt to open file: %s\n", filename);
    int e = lfs_file_open(GetFilesystem(), &file, filename, LFS_O_RDONLY);
    if(e < LFS_ERR_OK)
    {
        printf("file open error: %i\n", e);
    } 
    int size = lfs_file_size(GetFilesystem(), &file);
    e = lfs_file_read(GetFilesystem(), &file, incomingData, size);
    if(e < LFS_ERR_OK)
    {
        printf("file read error: %i\n", e);
    }
    lfs_file_close(GetFilesystem(), &file);
    printf("^^L%s^^E", incomingData);
    return 0;
}

static int DeleteFile()
{
    lfs_file_t file;
    // extract the filename
    char *s = incomingData;
    int searchCount = charCount;
    while(searchCount--)
    {
        if( *s++ == '^' )
        {
            if( *s++ == '^' )
            {
                if(*s == 'D')
                {
                    s++;
                    break;
                }
            }
        }
    }
    char filename[64];
    char *fn = filename;
    // extract the filename
    // TODO: deal with buffer overflow
    while(searchCount--)
    {
        if(*s != 0x03)
        {
            *fn = *s;
            s++; fn++;
        }
        else
        {
            break;
        }
    }
    *fn = 0;
    int e = lfs_remove(GetFilesystem(), filename);
    if(e < LFS_ERR_OK)
    {
        printf("file remove error: %i\n", e);
    }
    else
    {
        printf("file removed: %s\n", filename);
    }
    return 0;
}
lua_State *L;
#define UART_ID uart0

// void incoming_uart() {
//     while (uart_is_readable(UART_ID)) {
//         char ch = uart_getc(UART_ID);
//         incomingData[charCount++] = ch;
//         if(ch=='\r')
//             printf("\r\n");
//         else
//             printf("%c", ch);
//         // end of text / control c
//         if(ch == 0x03)
//         {
//             incomingData[--charCount] = 0;
//             printf("\n\n attempting to execute \n ----------------------- \n %s", incomingData);
//             int error = luaL_dostring(L, incomingData);
//             if (error) {
//                 printf("\n%s", lua_tostring(L, -1));
//                 lua_pop(L, 1);  /* pop error message from the stack */
//             }
//             charCount = 0;
//         }
//     }
// } 


static void echo_serial_port(uint8_t itf, uint8_t buf[], uint32_t count) {
  uint8_t const case_diff = 'a' - 'A';

  for (uint32_t i = 0; i < count; i++) {
    tud_cdc_n_write_char(itf, buf[i]);
  }
  tud_cdc_n_write_flush(itf);
}

// Invoked when device is mounted
void tud_mount_cb(void) {
}

// Invoked when device is unmounted
void tud_umount_cb(void) {
}
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
int main()
{
    board_init();
    tusb_init();

    L = luaL_newstate();   /* opens Lua */
    luaL_openlibs(L);
    int e = luaL_dostring(L, "print(collectgarbage(\"count\"))");
    if(e)
    {
        printf("%s\n", lua_tostring(L, -1));
    }

    lua_pushcfunction(L, l_setLed);
    lua_setglobal(L, "setLed");
    lua_pushcfunction(L, l_playNote);
    lua_setglobal(L, "playNote");
    lua_pushcfunction(L, l_setParam);
    lua_setglobal(L, "setParam");
    lua_pushcfunction(L, l_resetParams);
    lua_setglobal(L, "resetParams");
    lua_pushcfunction(L, l_getPot);
    lua_setglobal(L, "getPot");
    
    e = luaL_dostring(L, global_lua);
    if(e)
    {
        printf("%s\n", lua_tostring(L, -1));
    }

    hardware_init();

    sleep_ms(10);

    stdio_init_all();
    usb_printf_init();
    ws2812_init();
    memset(color, 0, 25 * sizeof(uint32_t));
    ws2812_setColors(color+5);
    ws2812_trigger();

    
    queue_init(&signal_queue, sizeof(queue_entry_t), 3);
    queue_init(&complete_queue, sizeof(queue_entry_complete_t), 2);
    queue_init(&renderCompleteQueue, sizeof(queue_entry_complete_t), 2);
    queue_entry_complete_t result;
    result.screenFlipComplete = true;
    result.renderInstrumentComplete = false;
    queue_add_blocking(&complete_queue, &result);
    multicore_launch_core1(draw_screen);
    struct repeating_timer timer;
    struct repeating_timer timer2;

    InitFilesystem();

    // if the user is holding down specific keys on powerup, then clear the full file system
    // InitializeFilesystem(hardware_get_key_state(0,4) && hardware_get_key_state(3, 4), get_rand_32());
    //usbSerialDevice.Init();
    gbox.init(color, L);

    memset(output_buf, SAMPLES_PER_SEND*2, sizeof(uint32_t));
    memset(capture_buf, SAMPLES_PER_SEND*2, sizeof(uint32_t));

    configure_audio_driver();
    hardware_post_audio_init();

    int step = 0;
    bool buttonState = false;
    bool lastButtonState = false;

    add_repeating_timer_ms(-33, repeating_timer_callback, NULL, &timer);

    int16_t touchCounter = 0x7fff;
    int16_t headphoneCheck = 60;
    uint8_t brightnesscount = 0;
    int lostCount = 0;
    int error = luaL_dostring(L, "function update() end");
    if (error) {
        fprintf(stderr, "%s", lua_tostring(L, -1));
        lua_pop(L, 1);  /* pop error message from the stack */
    }
    gbox.StartPlaying();

    lfs_dir_t scriptsDir;
    lfs_dir_open(GetFilesystem(), &scriptsDir, "scripts");
    struct lfs_info info;
    bool ranNextFile = false;
    while(lfs_dir_read(GetFilesystem(), &scriptsDir, &info) && !ranNextFile)
    {
        if(info.type == LFS_TYPE_REG)
        {
            char path[1024];
            sprintf(path, "scripts/%s", info.name);

            lfs_file_t file;
            // attempt to open this file
            lfs_file_open(GetFilesystem(), &file, path, LFS_O_RDONLY);
            lfs_file_read(GetFilesystem(), &file, incomingData, info.size);
            error = luaL_dostring(L, incomingData);
            if (error) {
                fprintf(stderr, "%s", lua_tostring(L, -1));
                lua_pop(L, 1);  /* pop error message from the stack */
                lfs_file_close(GetFilesystem(), &file);
            }
            // this should work fine, lets just go with it
            lfs_file_close(GetFilesystem(), &file);
            ranNextFile = true;
        }
    }


    while(true)
    {
        tud_task(); // tinyusb device task
        cdc_task();
        if(audioOutReady && audioInReady)
        {
            mutex_enter_blocking(&audioProcessMutex);
            for(int i=0;i<BLOCKS_PER_SEND;i++)
            {
                uint32_t *input = capture_buf+inBufOffset*SAMPLES_PER_SEND+SAMPLES_PER_BLOCK*i;
                uint32_t *output = output_buf+outBufOffset*SAMPLES_PER_SEND+SAMPLES_PER_BLOCK*i;
                gbox.Render((int16_t*)(output), (int16_t*)(input), SAMPLES_PER_BLOCK);
            }
            audioInReady = false;
            audioOutReady = false;
            mutex_exit(&audioProcessMutex);
        }
        else if(gbox.syncsRequired > 0)
        {
            int error = luaL_dostring(L, "tempoSync()");
            if (error) {
                fprintf(stderr, "%s", lua_tostring(L, -1));
                lua_pop(L, 1);  /* pop error message from the stack */
            }
            gbox.syncsRequired--;
        }
        else
        {
            lua_gc(L, LUA_GCSTEP, 1);
        }

        // button handler
        {
            bool btn = hardware_get_button_state();
            buttonState = hardware_get_button_state();
            if(buttonState && !lastButtonState)
            {
                // get the current files offset
                lfs_soff_t off = lfs_dir_tell(GetFilesystem(), &scriptsDir);

                // attempt to read next file
                bool stopFinding = false;
                while(!stopFinding)
                {
                    int res = lfs_dir_read(GetFilesystem(), &scriptsDir, &info);
                    if(res == 0)
                    {
                        lfs_dir_rewind(GetFilesystem(), &scriptsDir);
                        continue;
                    }
                    lfs_soff_t newOff = lfs_dir_tell(GetFilesystem(), &scriptsDir);
                    if(newOff == off)
                    {
                        char path[1024];
                        sprintf(path, "scripts/%s", info.name);
                        printf("only one file in scripts: %s\n", path);
                        stopFinding = true;
                        continue;
                    }
                    if(res >= 0 && info.type == LFS_TYPE_REG)
                    {
                        char path[1024];
                        sprintf(path, "scripts/%s", info.name);

                        lfs_file_t file;
                        // attempt to open this file
                        printf("attempt to open file: %s\n", path);
                        int e = lfs_file_open(GetFilesystem(), &file, path, LFS_O_RDONLY);
                        if(e < LFS_ERR_OK)
                        {
                            printf("file open error: %i\n", e);
                        }
                        e = lfs_file_read(GetFilesystem(), &file, incomingData, info.size);
                        if(e < LFS_ERR_OK)
                        {
                            printf("file read error: %i\n", e);
                        }
                        error = luaL_dostring(L, incomingData);
                        if (error) {
                            fprintf(stderr, "%s", lua_tostring(L, -1));
                            lua_pop(L, 1);  /* pop error message from the stack */
                            lfs_file_close(GetFilesystem(), &file);
                        }
                        // this should work fine, lets just go with it
                        lfs_file_close(GetFilesystem(), &file);
                        stopFinding = true;
                        continue;
                    }
                }
                
            }
            lastButtonState = buttonState;
        }

        if(needsScreenupdate)
        {
            gbox.OnAdcUpdate(hardware_get_adc_value());
            needsScreenupdate = false;
            hardware_update();
            int error = luaL_dostring(L, "update()");
            if (error) {
                fprintf(stderr, "%s", lua_tostring(L, -1));
                lua_pop(L, 1);
            }

        }
        
    }
    return 0;
}

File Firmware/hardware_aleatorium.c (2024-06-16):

#ifdef HARDWARE_ALEATORIUM

#include "hardware.h"
#include "ssd1306.h"

#define LINE_IN_DETECT 24
#define HEADPHONE_DETECT 16
#define row_pin_base 11
#define col_pin_base 6
#define BLINK_PIN_LED 25
#define USB_POWER_SENSE 29
#define SUBSYSTEM_RESET_PIN 21

// I2C defines
#define I2C_SDA 2
#define I2C_SCL 3

static bool last_amp_state;
static uint8_t battery_level;

i2c_dma_t* i2c_dma;

#include "hardware.h"
#include "ssd1306.h"

#define LINE_IN_DETECT 24
#define HEADPHONE_DETECT 16
#define row_pin_base 11
#define col_pin_base 6
#define BLINK_PIN_LED 25
#define USB_POWER_SENSE 29
#define SUBSYSTEM_RESET_PIN 21

// I2C defines
#define I2C_SDA 2
#define I2C_SCL 3

void hardware_init()
{
    // give all the caps some time to warm up
    sleep_ms(100);
    set_sys_clock_khz(200000, true);

    adc_init();
    adc_gpio_init(26);
    adc_select_input(0);
    
    i2c_init(I2C_PORT, 400*1000);

    gpio_init(23);
    gpio_set_dir(23, GPIO_IN);
    gpio_set_pulls(23, true, false);
    int gpioDownCount = 0;
    int gpioUpCount = 0;
    for(int i=0;i<10;i++)
    {
        if(!gpio_get(23))
        {
            gpioDownCount++;
        }
        else
        {
            gpioUpCount++;
        }
        sleep_ms(2);
    }

    if(gpioDownCount>gpioUpCount)
    {
        hardware_reboot_usb();
    }

}

void hardware_reboot_usb()
{
    reset_usb_boot(1<<BLINK_PIN_LED, 0);
}

void hardware_shutdown()
{
}

void hardware_post_audio_init()
{
}

bool hardware_get_button_state()
{
    // our main button state is inverted
    return gpio_get(23);
}

uint16_t hardware_get_adc_value()
{
    // our pot is wired backwards, invert
    return 0xfff-adc_read();
}

void hardware_update()
{
   // no op
}


#endif // HARDWARE_ALEATORIUM

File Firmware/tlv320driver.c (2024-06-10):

#include "tlv320driver.h"
#include "i2c_dma.h"

#define I2C_PORT i2c1
#define I2C_SDA 2
#define I2C_SCL 3
#define TLV_RESET_PIN 21
#define TLV_DEBUG 1
#define TLV_I2C_ADDR            0x18
#define TLV_REG_PAGESELECT	    0
#define TLV_REG_LDOCONTROL	    2
#define TLV_REG_RESET   	    1
#define TLV_REG_CLK_MULTIPLEX   	0x04

uint8_t currentPage = -1;
bool writeRegister(uint8_t reg, uint8_t val)
{
    uint8_t data[2];
    data[0] = reg;
    data[1] = val;
	int attempt=0;
	while (1) {
        attempt++;
        
        int ret = i2c_write_blocking(I2C_PORT, TLV_I2C_ADDR, data, 2, false);
        if (ret == 2) {
            #ifdef TLV_DEBUG
            printf("TLV320 write ok, %d tries\n", attempt);
            #endif
            return true;
        }
        if (attempt >= 12) {
            #ifdef TLV_DEBUG
            printf("TLV320 write failed, %d tries\n", attempt);
            #endif
            return false;
        }
        //sleep_us(80);
    }
}
bool readRegister(uint8_t page, uint8_t reg, uint8_t *rxdata)
{
    if(currentPage != page)
    {
        if(!writeRegister(0, page))
        {
            //printf("failed to go to page %i\n", page);
            return false;
        }
        currentPage = page;
    }

	int attempt=0;
	while (1) {
		attempt++;        
        int ret = i2c_write_blocking(I2C_PORT, TLV_I2C_ADDR, &reg, 1, true);
		if (ret == 1) {
            int ret;
            attempt = 0;
            ret = i2c_read_blocking(I2C_PORT, TLV_I2C_ADDR, rxdata, 1, false);
            if(ret == 1)
            {
                return true;
            }
            else
            {
                return false;
            }
        }
        if (attempt >= 12) {
            //printf("TLV320 read failed, %d tries\n", attempt);
            return false;
        }
        //sleep_us(80);
    }
}
bool write(uint8_t page, uint8_t reg, uint8_t val)
{
    if(currentPage != page)
    {
        if(!writeRegister(0, page))
        {
            //printf("failed to go to page %i\n", page);
            return false;
        }
        currentPage = page;
    }
    return writeRegister(reg, val);
}

void tlvDriverInit()
{
        // reset
    write(0, 0x01, 0x01);

    // configure pll dividers
    // our bitclock runs at 32x(sample_freq)
    // so with 44100 we use the following values
    // pllp 1 pllr 3 pllj 20 plld 0 MADC 3 NADC 5 AOSR 128 MDAC 3 NDAC 5 DOSR 128
    // 44100*32*3*20.0

    // use bitclock for pll input, pll for clock input
    write(0, 0x04, 0x07);

    // pll p & r & powerup
    write(0, 0x05, (0x01<<7)|(0x01<<4)|0x03);
    // pll j
    write(0, 0x06, 0x14);


    // ndac &p powerup
    write(0, 0x0b, 0x80|0x05);
    // mdac & powerup
    write(0, 0x0c, 0x80|0x03); // original settings
    write(0, 0x0c, 0x80|0x02); // messing around

    // adc clocks should be driven by dac clocks, so no power necessary
    // but you still need to set them correctly
    write(0, 0x12, 0x05);
    write(0, 0x13, 0x03);
    write(0, 0x13, 0x02); // messing around - as above

    // dosr 64
    write(0, 0x0d, 0x00);
    write(0, 0x0e, 0x40);

    // adc osr 64
    write(0, 0x14, 0x40);
    // Select ADC PRB_R7
    write(0, 0x3d, 0x07);

    // bitclock offset
    // write(0, 0x1c, 0x2);
    // bitclock polarity flip
    // write(0, 0x1d, 0x08);
    // word length
    // processing block? default doesn't have the beep generator :(
    // printf("setup clocks\n");
    // sleep_ms(1000);
    // printf("one second to power\n");
    // sleep_ms(1000);
    // printf("power\n");
    // power enable
    // disable internal avdd prior to powering up internal LDO
    write(1, 0x01, 0x08);
    // enable analog power blocks

    // common mode voltage
    //
    // set ref to slow powerup
    write(1, 0x7b, 0x00);
    // HP softstepping settingsfor optimal pop performance at power up
    // Rpopusedis 6k withN = 6 and softstep= 20usec.Thisshouldworkwith47uFcoupling
    // capacitor.Can try N=5, 6 or 7 time constants as well.Trade-offdelay vs “pop” sound.
    write(1, 0x14, 0x25);
    // enable LDO
    write(1, 0x02, 0x01);

    // setup headphones to be powered by ldo
    // and set LDO input to 1.8-3.3
    write(1, 0x0a, 0x4B);

    // Set MicPGA startup delay to 3.1ms
    write(1, 0x47, 0x32);
    
    // micbias must always be on to avoid noise
    // write(1, 0x33, 0x68); // micbias enable, 2.5v
    // write(1, 0x33, 0x54); // micbias enable, 1.7v LDO in generation
    //write(1, 0x33, 0x50); // micbias enable, 1.7v avdd  generation
    // write(1, 0x33, 0x74); // micbias enable, powersupply
    
    driver_set_mic(false);
    
    // // analog bypass & dac routed to headphones
    // write(1, 0x0c, 0x0a);
    // write(1, 0x0d, 0x0a);

    // // dac & mixer to headphones
    // write(1, 0x0c, 0x0a);
    // write(1, 0x0d, 0x0a);
    
    // route dac only to headphones
    write(1, 0x0c, 0x08);
    write(1, 0x0d, 0x08);

    // dac and mixer to lineout
    write(1, 0x0e, 0x08);
    write(1, 0x0f, 0x08);
    
    // Set the ADC PTM Mode to PTM_R1
    write(1, 0x3d, 0x01);
    // Set the HPL gain to 0dB
    write(1, 0x10, 0x00);
    write(1, 0x11, 0x00);
    write(1, 0x10, 0x0); //0x1d maximum for sync output
    write(1, 0x11, 0x0);
    
    // set lineout gain to 0  db
    write(1, 0x12, 0x0);
    write(1, 0x13, 0x0);
    // set lineout gain to 20 db
    write(1, 0x12, 10);
    write(1, 0x13, 10);

    // power up headphones & mixer amp
    write(1, 0x09, 0x33);

    // power up headphones, lineout & mixer amp
    write(1, 0x09, 0x3f);

    // Powerup the Left and Right DAC Channels
    write(0, 0x3f, 0xd6);
    // Unmutethe DAC digital volume control 
    write(0, 0x40, 0x00);
    //sleep_ms(200);
    //printf("powering up adc, lets go\n");
    sleep_ms(10);
    //printf("powering up adc, now\n");
    // power up ADC
    write(0, 0x51, 0xc0);
    write(0, 0x52, 0x00);

    // enable headphone detection
    write(0, 0x43, 0x80);
}
void driver_set_mute(bool mute)
{
    write(1, 0x10, mute?0x40:0x00);
    write(1, 0x11, mute?0x40:0x00);
}
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

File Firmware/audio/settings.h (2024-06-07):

// Copyright 2012 Emilie Gillet.
//
// Author: Emilie Gillet (emilie.o.gillet@gmail.com)
//
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
// See http://creativecommons.org/licenses/MIT/ for more information.
//
// -----------------------------------------------------------------------------
//
// Settings

#ifndef BRAIDS_SETTINGS_H_
#define BRAIDS_SETTINGS_H_

namespace braids {

const char* const algo_values[] = {
    "CSAW",
    "/\\-_",
    "//-_",
    "FOLD",
    "UUUU",
    "SUB-",
    "SUB/",
    "SYN-",
    "SYN/",
    "//x3",
    "-_x3",
    "/\\x3",
    "SIx3",
    "RING",
    "////",
    "TOY*",
    "ZLPF",
    "ZPKF",
    "ZBPF",
    "ZHPF",
    "VOSM",
    "VOWL",
    "VFOF",
    "HARM",
    "FM  ",
    "FBFM",
    "WTFM",
    "BELL",
    "DRUM",
    "KICK",
    "CYMB",
    "SNAR",
    "WTBL",
    "WMAP",
    "WLIN",
    "WTx4",
    "NOIS",
    "TWNQ",
    "CLKN",
    "CLOU",
    "PRTC",
    "QPSK",
    // "NAME" // For your algorithm
};

enum MacroOscillatorShape {
  MACRO_OSC_SHAPE_CSAW,
  MACRO_OSC_SHAPE_MORPH,
  MACRO_OSC_SHAPE_SAW_SQUARE,
  MACRO_OSC_SHAPE_SINE_TRIANGLE,
  MACRO_OSC_SHAPE_BUZZ,
  
  MACRO_OSC_SHAPE_SQUARE_SUB,
  MACRO_OSC_SHAPE_SAW_SUB,
  MACRO_OSC_SHAPE_SQUARE_SYNC,
  MACRO_OSC_SHAPE_SAW_SYNC,
  MACRO_OSC_SHAPE_TRIPLE_SAW,
  MACRO_OSC_SHAPE_TRIPLE_SQUARE,
  MACRO_OSC_SHAPE_TRIPLE_TRIANGLE,
  MACRO_OSC_SHAPE_TRIPLE_SINE,
  MACRO_OSC_SHAPE_TRIPLE_RING_MOD,
  MACRO_OSC_SHAPE_SAW_SWARM,
  MACRO_OSC_SHAPE_TOY,

  MACRO_OSC_SHAPE_DIGITAL_FILTER_LP,
  MACRO_OSC_SHAPE_DIGITAL_FILTER_PK,
  MACRO_OSC_SHAPE_DIGITAL_FILTER_BP,
  MACRO_OSC_SHAPE_DIGITAL_FILTER_HP,
  MACRO_OSC_SHAPE_VOSIM,
  MACRO_OSC_SHAPE_VOWEL,
  MACRO_OSC_SHAPE_VOWEL_FOF,
  
  MACRO_OSC_SHAPE_HARMONICS,

  MACRO_OSC_SHAPE_FM,
  MACRO_OSC_SHAPE_FEEDBACK_FM,
  MACRO_OSC_SHAPE_CHAOTIC_FEEDBACK_FM,

  MACRO_OSC_SHAPE_STRUCK_BELL,
  MACRO_OSC_SHAPE_STRUCK_DRUM,
  MACRO_OSC_SHAPE_KICK,
  MACRO_OSC_SHAPE_CYMBAL,
  MACRO_OSC_SHAPE_SNARE,

  MACRO_OSC_SHAPE_WAVETABLES,
  MACRO_OSC_SHAPE_WAVE_MAP,
  MACRO_OSC_SHAPE_WAVE_LINE,
  MACRO_OSC_SHAPE_WAVE_PARAPHONIC,

  MACRO_OSC_SHAPE_FILTERED_NOISE,
  MACRO_OSC_SHAPE_TWIN_PEAKS_NOISE,
  MACRO_OSC_SHAPE_CLOCKED_NOISE,
  MACRO_OSC_SHAPE_GRANULAR_CLOUD,
  MACRO_OSC_SHAPE_PARTICLE_NOISE,
  
  MACRO_OSC_SHAPE_DIGITAL_MODULATION,

  MACRO_OSC_SHAPE_QUESTION_MARK,
  // MACRO_OSC_SHAPE_YOUR_ALGO
  MACRO_OSC_SHAPE_LAST,
  MACRO_OSC_SHAPE_LAST_ACCESSIBLE_FROM_META = MACRO_OSC_SHAPE_DIGITAL_MODULATION
};

enum Resolution {
  RESOLUTION_2_BIT,
  RESOLUTION_3_BIT,
  RESOLUTION_4_BIT,
  RESOLUTION_6_BIT,
  RESOLUTION_8_BIT,
  RESOLUTION_12_BIT,
  RESOLUTION_16_BIT,
  RESOLUTION_LAST
};
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

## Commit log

2024-06-08 cleanup and clarify final mix stage
2024-06-10 tlv320aic3204 driver version
2024-06-16 global volume starts at zero so we don't get a pop at the beginning while the ADC settles.
2024-06-21 Correct for crossplatform build
    [Midi.cc]

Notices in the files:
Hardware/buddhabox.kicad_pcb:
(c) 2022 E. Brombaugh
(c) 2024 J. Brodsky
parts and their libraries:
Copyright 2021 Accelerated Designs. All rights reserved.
